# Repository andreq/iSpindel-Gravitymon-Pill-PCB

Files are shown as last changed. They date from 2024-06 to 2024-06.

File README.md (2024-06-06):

# iSpindel Gravitymon Pill PCB
 A PCB used to build an iSpindel or GravityMon hydrometer that fit into a popular brand Pill casing instead of a PETling container.  
 Compatible with D1 Mini, C3, S2 and S3 mini esp board.

# Building tips
 Use the same components as most iSpindel PCB found online.  
 Remove the pin header plastic on the D1 mini (or equivalent) pins.  
 The D1 Mini need to be soldered as close as possible to the Pill PCB (between 1.5 to 1.9mm spacing between both board; Less is better).  
 The battery holder metal tabs need to be cut slightly to fit on the Pill PCB smaller pads.  
 Follow iSpindle build instructor for most of the other parts.  
 Only install the 470k voltade divider resitor for Esp32 based boards (C3, S2 and S3 mini).  
 The switch lever should be far away from the Pill casing, but might need to be shortened depanding on your switch.

# THIS IS A WIP !!!
 The latest PCB itteration was not produced yet, but should fit in a Pill casing.  
 My initial prototype needed a bit of sanding, will update as soon as first rev is tested.  
 I've only tested with a D1 mini, but the schematic and pcb fit Gravitiymon requirements for C3, S2 and S3 Mini.

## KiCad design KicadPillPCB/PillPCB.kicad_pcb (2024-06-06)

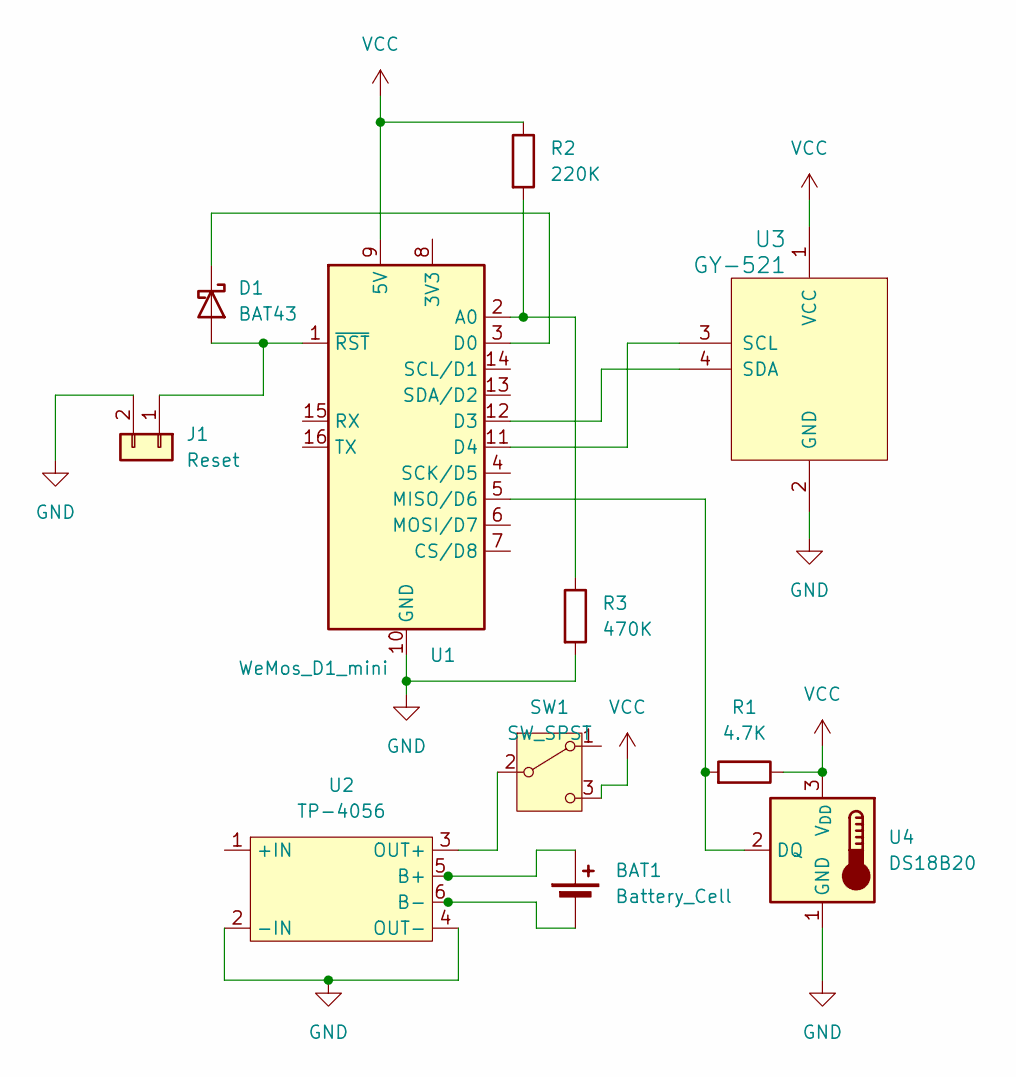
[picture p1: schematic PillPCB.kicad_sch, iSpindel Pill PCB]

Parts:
BAT1: Battery_Cell; BatteryHolder_Keystone_1042_1x18650_larger_slot
D1: BAT43; D_DO-35_SOD27_P7.62mm_Horizontal
J1: Reset; PinHeader_1x02_P2.54mm_Vertical
R1: 4.7K; Resistor
R2: 220K; Resistor
R3: 470K; Resistor
SW1: SW_SPST; SW_CuK_OS102011MA1QN1_SPDT_Angled
U1: WeMos_D1_mini; WEMOS_D1_mini_light_less_pins
U2: TP-4056; TP4056-Module
U3: GY-521
U4: DS18B20; TO-92_Inline

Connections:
GND: J1.2, R3.2, U1.10 (GND), U2.2 (-IN), U2.4 (OUT-), U3.2 (GND), U4.1 (GND)
unnamed: BAT1.1 (+), U2.5 (B+)
unnamed: BAT1.2 (-), U2.6 (B-)
unnamed: D1.2 (A), J1.1, U1.1 (~RST)
unnamed: D1.1 (K), U1.3 (D0)
unnamed: SW1.2 (B), U2.3 (OUT+)
unnamed: R2.2, R3.1, U1.2 (A0)
unnamed: U1.12 (D3), U3.4 (SDA)
unnamed: U1.11 (D4), U3.3 (SCL)
unnamed: R1.2, U1.5 (MISO/D6), U4.2 (DQ)
VCC: R1.1, R2.1, SW1.3 (C), U1.9 (5V), U3.1 (VCC), U4.3 (V_{DD})

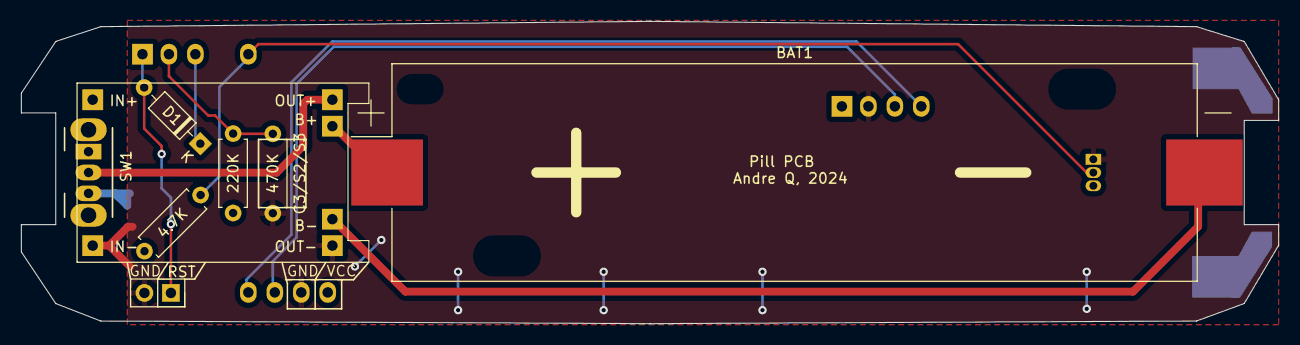
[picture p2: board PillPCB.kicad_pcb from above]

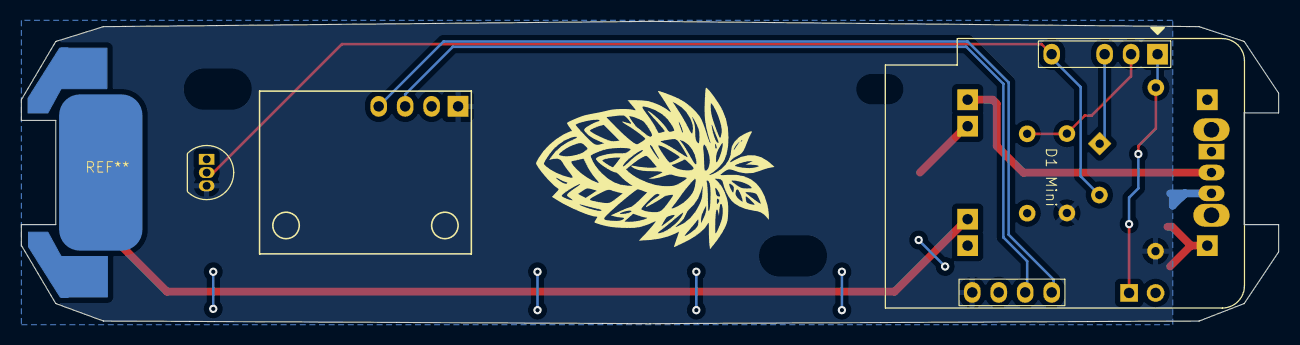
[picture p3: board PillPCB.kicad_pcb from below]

Board: 2 copper layers, 120.6 x 29.0 mm, 11 parts (3 on the bottom side), 11 nets.

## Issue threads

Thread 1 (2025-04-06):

tilt angle issue

xxyzuo, 2025-04-06:
Are you adding counterweight blocks to the bottom of the cell to maintain a good tilt angl.
After I made the finished product, I found that the tilt angle in pure water was very small, which resulted in a very small amount of change in tilt angle from high specific gravity to pure water, which could cause the specific gravity calculations to be wildly inaccurate.

andreq, 2025-04-06:
There's some solder pads at the bottom that you thin as much as possible to add weight. It's the same idea from "The Jeffrey 2.69" pcb from opensourcedistilling.

xxyzuo, 2025-04-07:
I see, the bottom pad does what I thought it would do; can you tell me roughly how many grams of solder are needed to achieve the right angle?

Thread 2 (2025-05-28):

Any follow up of this project ?

sigma415, 2025-05-28:
I have found this project here:  https://www.homebrewtalk.com/threads/ispindel-gravitymon-pill-pcb.732700/

There you have announced some more build instructions with photos.
Any update of this available ?

andreq, 2025-05-28:
Life got in the way and this got side tracked.

The assembly instruction from https://opensourcedistilling.com/ispindel-assembly/ are still the best to follow.
The slight difference would be for using ESP-C3(or S2 or S3) where you need to add a 470k pull-up resistor.

I'll see if I can take some time to add some quick instruction photos using one of my prototype PCB.

Thanks for the interest in the project, it does give me some motivation to update the repository.

mp-se, 2025-06-06:
Good to see that someone is building pcb's for gravitymon and esp32. keep up the good work. Have you tested the last iteration ?

andreq, 2025-06-07:
I have yet to fab the current PCB on this repo, but the only changes vs my prototype are some graphic on the silk screen and slight tweak to the pcb size so it fit without needed to be sanded.

Still havent taken time to do an assembly "photoshoot"... it'll come.. it'll come :)
